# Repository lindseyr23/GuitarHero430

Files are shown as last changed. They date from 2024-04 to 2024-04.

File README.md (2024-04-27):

# Guitar Hero 430
## Rice University ELEC 327 Final Project Spring '24

## Project Description 
This project aims to recreate the experience of playing the iconic Guitar Hero using MSP430 microcontrollers. Inspired by the popular rhythm-based video game, this project combines hardware interfacing, LED visualization, audio processing, and gameplay logic to create an experience playing along with your favorite songs.

Using two TI LaunchPad Kits with MSP430 (MSP-EXP430G2ET), the project simulates the Guitar Hero gameplay. One LaunchPad serves as the game controller, managing gameplay logic and capturing user input, while providing real-time feedback through an LED display. The other LaunchPad controls LED visualizations and audio output for the song.

Upon starting the game, users are greeted with an introduction sequence. They can select song 1 by pressing the green button or song 2 by pressing the blue button. During gameplay, missing too many notes results in a loss sequence. However, achieving a streak of a certain number of notes resets the missed notes counter, akin to the rock meter in Guitar Hero. Successfully completing the entire song triggers a win sequence.

Check out a demo of the project [here](https://youtu.be/caU7hopNlVo)!

## Table of Contents
1. [Project Description](#project-description)
2. [Team Members](#team-members)
3. [Materials](#materials)
4. [File Descriptions](#file-descriptions)
5. [Setting up the Hardware](#setting-up-the-hardware)
   - [LED Game Display Setup Guide](#led-game-display-setup-guide)
   - [LED User Display Setup Guide](#led-user-display-setup-guide)
   - [3D-Printed Strummer & LED Game Display Case Setup Guide](#3D-Printed-Strummer-&-LED-Game-Display-Case-Setup-Guide)
   - [Schematic](#schematic)
6. [Installation](#installation)
7. [References](#references)

### Team Members
- Natalia Mendiola | nm58@rice.edu
- Lindsey Russ     | ltr1@rice.edu
  
---
### Materials

* 2x computers 
* 2x TI LaunchPad Kit with MSP430 ([MSP-EXP430G2ET](https://www.ti.com/lit/ug/slau144k/slau144k.pdf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))
* 2x 330 Ω Resistors
* 1x SunFounder I2C LCD1602 Module _(we used [this](https://www.sunfounder.com/products/i2c-lcd1602-module))_
* 5x Push Buttons _(we used [these](https://www.amazon.com/Gikfun-12x12x7-3-Tactile-Momentary-Arduino/dp/B01E38OS7K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) )_
* SK9822 LED Strips
* Solderless Breadboard
* Jumper wires
* Enameled wire

### Required Software Packages

* **Code Composer Studio (CSS)**
  - Install Code Composer Studio on two separate computers. Download it from [here](https://www.ti.com/tool/download/CCSTUDIO/12.7.0).
* **Python**
  - This project is compatible with Python 3.11.x. Make sure you have Python 3.11.x installed on your system before installing the required packages. To install the required Python packages, run the following command in your terminal or command prompt:
   ```python
   pip install -r requirements.txt
   ```
----
## File Descriptions

### Board 1:

* **Game Logic:**
  - [main.c](./board1/main.c): Handles game logic and user inputs.
    
* **User LED Display Logic:**
  - [rgb_interface_user.c](./board1/rgb_interface_user.c): Controls RGB LEDs via SPI communication.
  - [rgb_interface_user.h](./board1/rgb_interface_user.h): Header file for RGB user interface.
    
* **Scoreboard LCD Display Logic:**
  - [i2c.c](./board1/i2c.c): Initializes and transmits data over the I2C bus.
  - [i2c.h](./board1/i2c.h): Header file for I2C communication.
  - [lcd.c](./board1/lcd.c): Implements functions for interacting with an LCD display using I2C communication.
  - [lcd.h](./board1/lcd.h): Header file for LCD interface.

### Board 2:

* **Game Audio and Visual Logic:**
  - [main.c](./board2/main.c): Handles receiving communication from Board 1 to trigger events on the 5x7 LED screen and play MP3 files

* **LED Game Display Logic:**
  - [rgb_interface.c](./board2/rgb_interface.c): Controls the 5x7 LED Screen via SPI communication
  - [rgb_interface.h](./board2/rgb_interface.h): Header file for RGB interface

* **Audio:**
  - [receive_audio.py](./board2/receive_audio.py): Reads in data from the COM port to trigger the MP3 files playing and stopping
  - [PlaySong.c](./board2/PlaySong.c): Sends out the information to the COM port using UART communication to trigger the python file
  - [PlaySong.h](./board2/PlaySong.h): Header file for PlaySong
  - [Rock_Band_4_Fortunate_Son_Creedence_Clearwater_Revival_Full_Band_HD.mp3](./board2/Rock_Band_4_Fortunate_Son_Creedence_Clearwater_Revival_Full_Band_HD.mp3): Song 1
  - [Guitar_Hero_3_Mississippi_Queen.mp3](./board2/Guitar_Hero_3_Mississippi_Queen.mp3): Song 2
  - [win_sound_effect.mp3](./board2/win_sound_effect.mp3): Winning sound effect
  - [loss_sound_effect.mp3](./board2/loss_sound_effect.mp3): Losing sound effect

---

## Setting up the hardware

### LED Game Display Setup Guide
<div style="text-align:center">
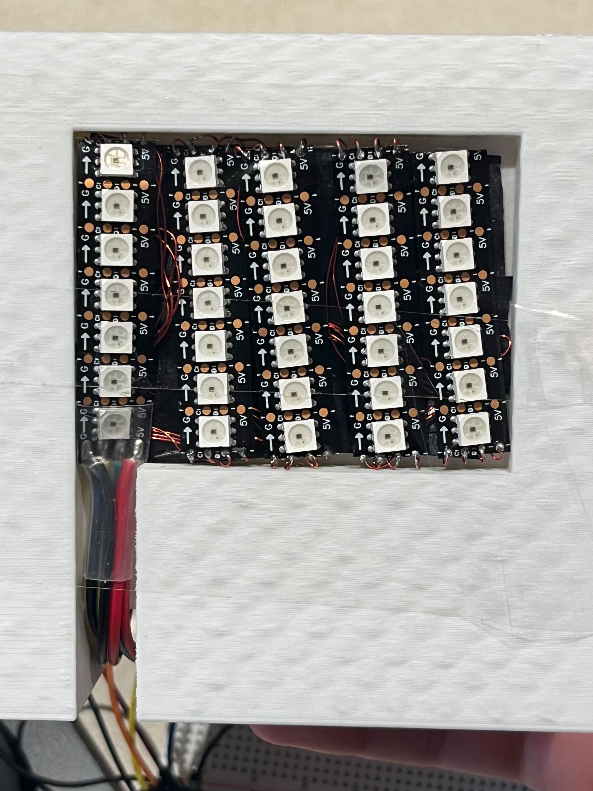
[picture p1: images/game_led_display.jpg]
LED Game Display
  
</div>

#### Components Needed:
   - SK9822 LED strips
   - Jumper wires (male-to-female)
   - Enameled wire
   - Heat shrink tubing
   - Electrical Tape

#### Instructions:
1. **Prepare the LED Strip:**
   - Cut five 7-LED long strips from the SK9822 LED strip.
2. **Solder Jumper Wires:**
   - For only ONE LED strip, solder four jumper wires to one end:
     - G (Ground)
     - C (Clock)
     - D (Data)
     - 5V (Power)
3. **Attach Female Connectors:**
   - (if not already present) Solder female connectors to the other end of the jumper wires for this LED strip.
4. **Connect LED Strips:**
   - For the remaining four strips, connect each strip to the previous one using enameled wire:
     - Connect G to G, C to C, D to D, and 5V to 5V.
     - Hide the enameled wire connections behind the LED strips.
     - Daisy-chain the five LED strips together, ending with the jumper wires side.
5. **Secure Connections:**
   - Use electrical tape to secure the enameled wire connections behind the LED-facing side of the LED strips, forming a 5x7 LED rectangular shape.
   - Use heat shrink tubing to insulate and secure the jumper wire soldered connections.
#### Notes:
   - Handle the soldering iron and heat shrink tubing carefully to prevent injuries or damage to components.

### LED User Display Setup Guide
<div style="text-align:center">
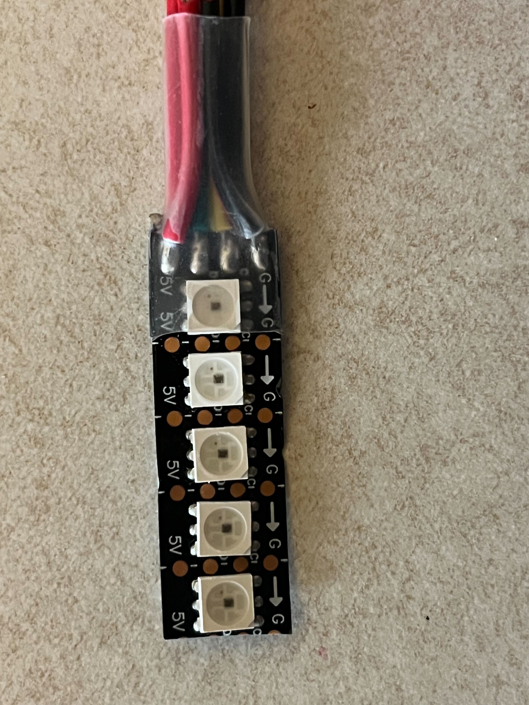
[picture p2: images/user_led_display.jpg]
LED User Display
    
</div>

#### Components Needed:
   - SK9822 LED strips
   - Jumper wires (male-to-female)
   - Heat shrink tubing

#### Instructions:
1. **Prepare the LED Strip:**
   - Cut a 5 LED long strip from the SK9822 LED strip.
2. **Solder Jumper Wires:**
   - Solder four jumper wires to one end of the LED strip:
     - One wire for G (Ground)
     - One wire for C (Clock)
     - One wire for D (Data)
     - One wire for 5V (Power)
3. **Attach Female Connectors:**
   - (if not already present) Solder female connectors to the other end of the jumper wires.
4. **Secure Connections:**
   - Use heat shrink tubing to insulate and secure the soldered connections.
#### Notes:
   - Handle the soldering iron and heat shrink tubing carefully to prevent injuries or damage to components.

### 3D-Printed Strummer & LED Game Display Case Setup Guide:
* [Strumbar STL File](./stl_files/strumbar2b-v3.stl)
* [End Bracket STL File](./stl_files/endbracket-v26.stl)
* [LED Display Holder STL File](./led_display_holder.stl)

3D Print the Strumbar, 2 of the End Brackets, and  the LED Display Holder from the above STL files. The Strumbar and End Brackets may need to be resized, in which case resize them both with the same ratio, ensuring that it is large enough for a button to fit within the notch but not too large so that the strumbar is unable to reach the button. We found that a width of 3 inches worked well for the Strumbar. The brackets for the strummer can be screwed onto a PCB, or taped down to a breadboard. The notch in the strummer is where the button for strumming input should be set up.

Secure the 5x7 LED display within the 3D-printed holder, with the jumper wires going through the notch and routed to the back for connection to the MSP430 acting as board 
2. 

### Schematic

#### Overall Schematic:
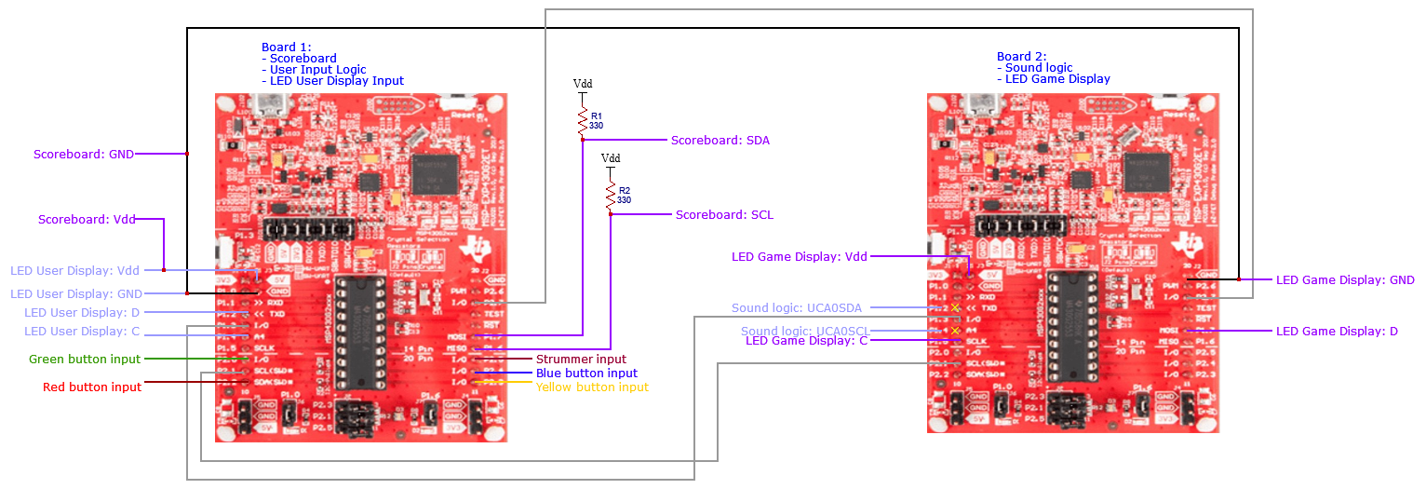
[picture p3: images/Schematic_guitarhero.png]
Overall Schematic


#### Board 1:
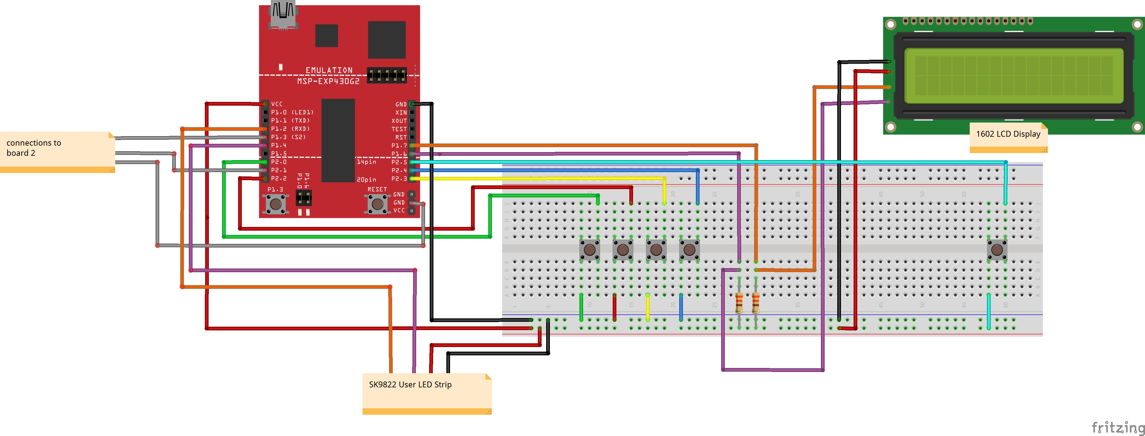
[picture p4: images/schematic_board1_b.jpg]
Board 1


#### Board 2:
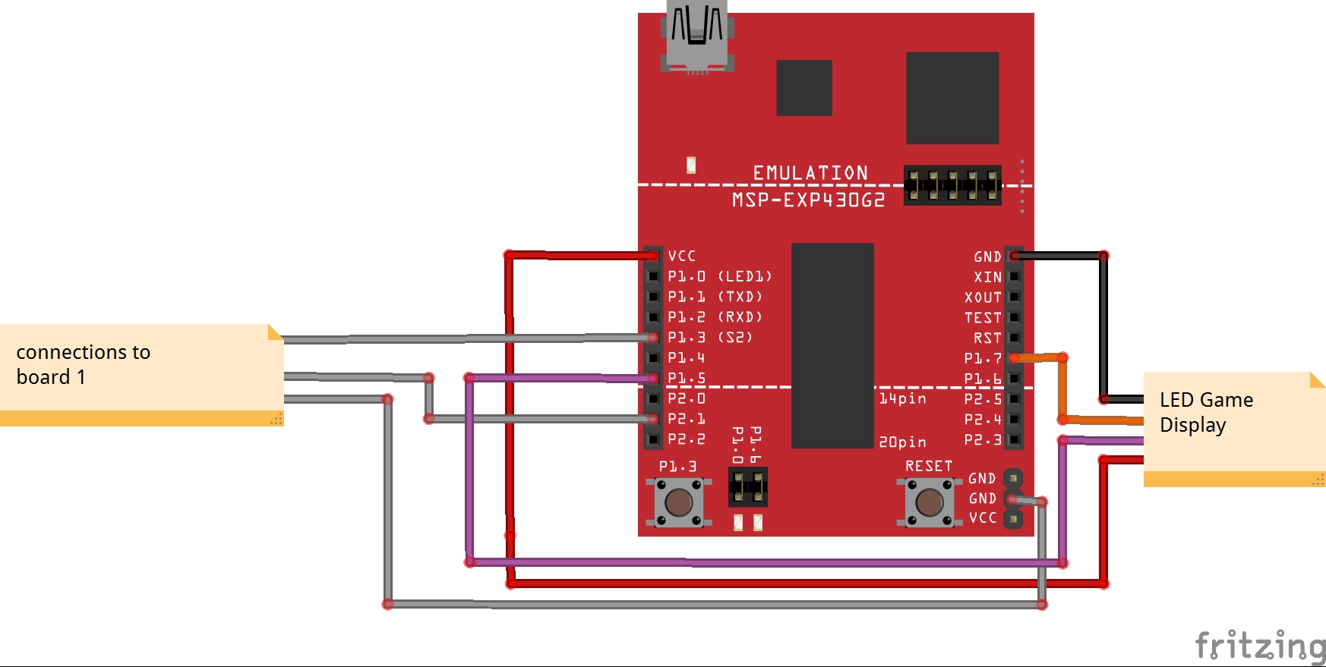
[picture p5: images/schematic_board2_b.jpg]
Board 2


---

## Installation

1. **Set up the Hardware:**
   - Follow the schematics to set up the circuit boards for both LaunchPads.
        -  [Overall Schematic](./images/Schematic_guitarhero.png)
        -  [Board 1 schematic](./images/schematic_board1_b.jpg)
        -  [Board 2 schematic](./images/schematic_board2_b.jpg)

2. **Install Code Composer Studio:**
    - Download and install [Code Composer Studio](https://www.ti.com/tool/download/CCSTUDIO/12.7.0) on your computer.

3. **Create Projects for Each Board:**
   - OpenCode Composer Studio
   - Create a separate project for each board.
   - Set the target device to MSP430G2553 for each project.

4. **Set up the LaunchPads:**
   - Upload the board 2 code to the LaunchPad set up as board 2.
   - Then, upload the board 1 code for LaunchPad set up as board 1.

5. **Run receive_audio.py Script:**
   - On the same computer running board 2 code, run a script named "receive_audio.py".

6. **Have fun!**
   - Start the game, and you'll be greeted with an intro sequence.
   - Choose a song by pressing the green button for song 1 or the blue button for song 2.
   - During gameplay, hitting the buttons correctly will keep the music going. Missing too many notes will lead to a game over sequence.
   - Just like in Guitar Hero, hitting a streak of notes will reset your missed notes counter.
   - Completing the entire song will trigger a win sequence!
  
#### Note: 
   - Feel free to explore and customize the code to add more songs, difficulty levels, or even different instruments!
---

## References
1. _Strumbar - with “finger notches”_ stl file from [Byte Arts](https://www.bytearts.com/strumfixplus).
2. Modified code by Dr. Joseph Young based on [I2C Display and MSP430](https://github.com/andrei-cb/I2C-Display-and-MSP430/tree/master) by Andrei-cb.

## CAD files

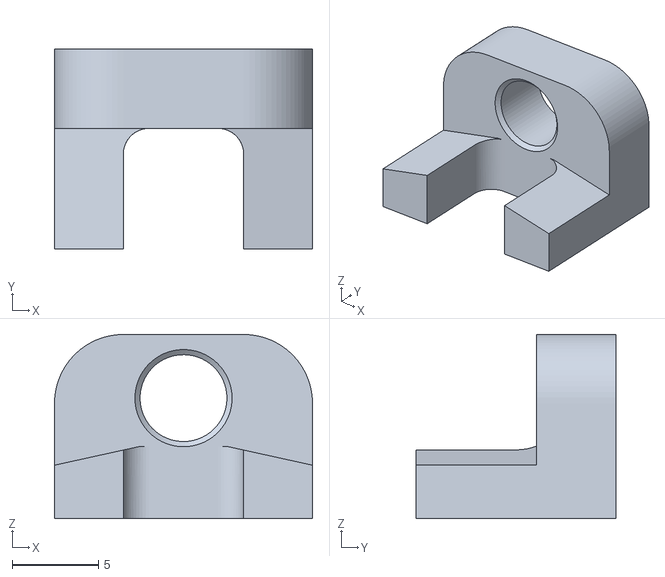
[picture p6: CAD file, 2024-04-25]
stl_files/endbracket-v26.stl
15.0 x 11.6 x 10.7

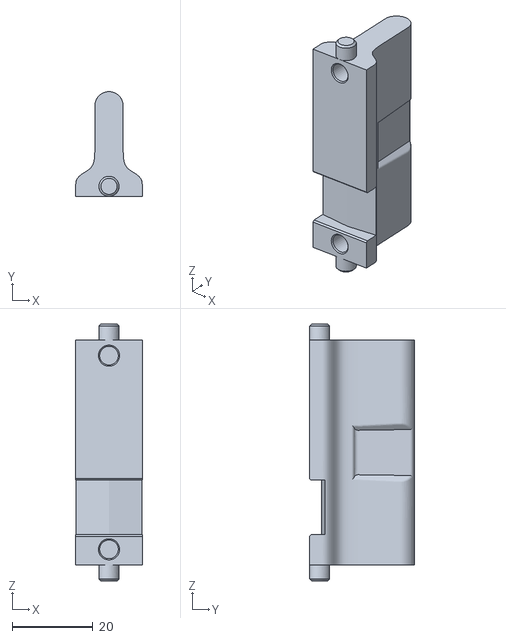
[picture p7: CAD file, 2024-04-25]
stl_files/strumbar2b-v3.stl
16.5 x 26.0 x 63.8

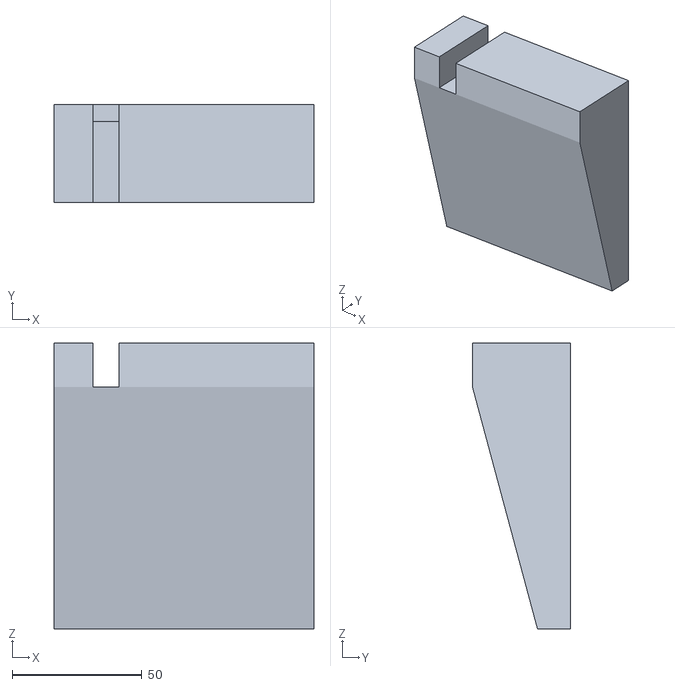
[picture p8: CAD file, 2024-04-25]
stl_files/led_display_holder.stl
100.0 x 37.7 x 110.0

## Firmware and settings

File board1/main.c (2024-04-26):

#include <stdio.h>
#include <string.h>

#include "rgb_interface_user.h"
//------------------------------
#include "lcd.h"
#include "msp430g2553.h"


/*
 * Connections Necessary:
 *
 * Green Button: 2.0 Red 2.2 Yellow 2.3 Blue 2.4
 * Strummer: 2.5
 */
/*
green - 1; red - 2; yellow - 3; blue - 4;
green/red - 5; green/yellow -6; green/blue - 7;
red/yellow - 8; red/blue - 9; yellow/blue - 10;
*/
const unsigned int song1[] = {//Fortunate Son - Creedence Clearwater Revival
                           0,0,0,0,0,0,0,0, //intro
                           0,0,0,0,0,0,0,0,
                           0,0,0,0,0,0,0,0, //
                           0,0,0,0,0,0,0,0,
                            3,4,4,4,4,4,4,4, //0:07
                            2,3,3,3,3,3,3,3,
                            1,3,3,3,3,3,3,3,
                            1,2,2,2,3,1,1,1,
                            3,4,4,4,4,4,4,4,
                            2,3,3,3,3,3,3,3,
                            1,3,3,3,3,3,3,3,
                            1,2,2,2,3,1,1,1,
                            9,0,0,9,0,9,9,0, //verse 1? 0:21
                            6,0,0,6,0,6,0,0,
                            10,0,0,10,0,10,0,0,
                            9,0,4,3,0,2,3,2,
                            2,2,2,2,2,2,2,2,
                            6,0,0,6,0,6,0,0,
                            10,0,0,10,0,10,0,0,
                            2,2,1,2,3,2,4,2,
                            2,2,2,2,2,2,2,2, //0:35
                            1,1,1,3,3,3,3,3,
                            2,2,2,4,4,4,3,3,
                            2,1,3,1,4,1,2,1,
                            3,3,3,3,3,3,3,3,//0:35
                            1,1,1,3,3,3,3,3,
                            2,2,2,4,4,4,3,3,
                            1,1,4,4,3,2,1,3,
                            2,2,2,2,2,2,2,2,//0:36
                            1,1,1,3,3,3,3,3,
                            2,2,2,4,4,4,3,3,
                            1,1,4,4,3,2,1,3,
                            2,2,2,2,2,2,2,2,
                            2,2,2,2,2,2,2,2,//0:43
                            1,1,1,3,3,3,3,3,
                            2,2,2,4,4,4,3,3,
                            1,1,4,4,3,2,1,3,
                            2,2,2,2,2,2,2,2,//0:50
                            6,0,0,6,0,6,0,0,
                            10,0,0,10,0,10,0,0,
                            9,0,4,3,0,2,3,2,
                            2,2,2,2,2,2,2,2, //0:57
                            6,0,0,6,0,6,0,0,
                            10,0,0,10,0,10,0,0,
                            9,0,4,3,0,2,3,2,
                            2,2,2,2,2,2,2,2,//1:04
                            1,1,1,3,3,3,3,3,
                            2,2,2,4,4,4,3,3,
                            1,1,4,4,3,2,1,3,
                            2,2,2,2,2,2,2,2,
                            1,1,1,3,3,3,3,3,
                            2,2,2,4,4,4,3,3,
                            1,1,4,4,3,2,1,3,
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
                            2,2,2,2,2,2,2,2,//1:48 it aint me
                             1,1,1,3,3,3,3,3,
                             2,2,2,4,4,4,3,3,
                             1,1,4,4,3,2,1,3,
                             2,2,2,2,2,2,2,2,
                             1,1,1,3,3,3,3,3,
                             2,2,2,4,4,4,3,3,
                             1,1,4,4,4,4,1,3,
                             2,2,2,2,2,2,2,2,
                             1,1,1,3,3,3,3,3,
                             2,2,2,4,4,4,3,3,
                             1,1,4,4,4,4,1,3,
                             2,2,2,2,2,2,2,2,
                             1,1,1,3,3,3,3,3,
                             2,2,2,4,4,4,3,3,
                             1,1,4,4,4,4,1,3,
                             2,2,2,2,2,2,2,2,
                             0,0,0,0,0,0,0,0};

const unsigned int songLength1 = sizeof(song1) / sizeof(song1[0]);

unsigned int song2[] = {//Mississippi Queen - Mountain
                        0,0,0,0,0,0,0,0, //into
                        0,0,0,0,0,0,0,0,
                        0,0,0,0,0,1,2,4,
                        2,2,2,0,0,0,0,0,
                        0,0,0,0,0,1,2,4,
                        2,2,2,0,0,0,0,0,
                        3,4,3,2,1,1,3,1    //0:15
                        0,1,2,3,4,4,2,2,
                        1,2,3,4,1,1,2,3
//                        3,4,3,2,1,1,2,3,
//                        5,5,0,0,0,0,0,0, //0:22
//                        0,1,4,1,2,2,3,3, //0:24
//                        5,0,6,0,6,6,6,6,
//                        0,1,4,1,2,2,2,2,
//                        5,0,6,0,6,6,6,6,
//                        0,1,4,1,2,2,3,3,
//                        5,0,6,0,6,6,6,6,
//                        0,1,4,1,2,2,2,2,
//                        8,0,9,9,9,9,9,9,//0:36
//                        0,2,3,2,3,3,4,4,
//                        8,0,9,9,9,9,9,9,
//                        0,0,0,2,3,2,4,4,
//                        5,0,6,0,6,6,6,6, //0:42
//                        0,1,4,1,2,2,2,2

                                        //0:50 changes slightly
};

const unsigned int songLength2 = sizeof(song2) / sizeof(song2[0]);

volatile unsigned int current_note;
volatile unsigned int missed_note;
volatile unsigned int streak;

int user_LED_1;
int user_LED_2;
int user_LED_3;
int user_LED_4;
int button_press_detected;
int strummer;
int score;
int Q=6;
int duration_counter;

volatile unsigned int curr_note;

int song; //takes 1 for song1, 2 for song 2
int debounce_counter;

void check_input(){

    if (song == 1){
        curr_note = song1[current_note];
    }
    else if (song == 2){
       curr_note = song2[current_note];
    }

        switch(curr_note) { //checks if note is correct
            case 1: //green
                if (1 == user_LED_1 & 0 == user_LED_2 & 0 == user_LED_3 & 0 == user_LED_4){
                    score += 10;
                    streak++;
                }
                else {
                    missed_note++;
                    streak = 0;
                }
                break;
            case 2://red
                if (0 == user_LED_1 & 1 == user_LED_2 & 0 == user_LED_3 & 0 == user_LED_4){
                    score += 10;
                    streak++;
                }
                else {
                    missed_note++;
                    streak = 0;
                }
                break;
            case 3: //yellow
                if (0 == user_LED_1 & 0 == user_LED_2 & 1 == user_LED_3 & 0 == user_LED_4){
                    score += 10;
                    streak++;
                }
                else {
                    missed_note++;
                    streak = 0;
                }
                break;
            case 4: //blue
                if (0 == user_LED_1 & 0 == user_LED_2 & 0 == user_LED_3 & 1 == user_LED_4){
                    score += 10;
                    streak++;
                }
                else {
                    missed_note++;
                    streak = 0;
                }
                break;
            case 5: //green/red
                if (1 == user_LED_1 & 1 == user_LED_2 & 0 == user_LED_3 & 0 == user_LED_4){
                    score += 10;
                    streak++;
                }
                else {
                    missed_note++;
                    streak = 0;
                }
                break;
            case 6: //green/yellow
                if (1 == user_LED_1 & 0 == user_LED_2 & 1 == user_LED_3 & 0 == user_LED_4){
                    score += 10;
                    streak++;
                }
                else {
                    missed_note++;
                    streak = 0;
                }
                break;
            case 7: //green/blue
                if (1 == user_LED_1 & 0 == user_LED_2 & 0 == user_LED_3 & 1 == user_LED_4){
                    score += 10;
                    streak++;
                }
                else {
                    missed_note++;
                    streak = 0;
                }
                break;
            case 8: //red/yellow
                if (0 == user_LED_1 & 1 == user_LED_2 & 1 == user_LED_3 & 0 == user_LED_4){
                    score += 10;
                    streak++;
                }
                else {
                    missed_note++;
                    streak = 0;
                }
                break;
            case 9: //red/blue
                if (0 == user_LED_1 & 1 == user_LED_2 & 0 == user_LED_3 & 1 == user_LED_4){
                    score += 10;
                    streak++;
                }
                else {
                    missed_note++;
                    streak = 0;
                }                
                break;
            case 10:// yellow/blue
                if (0 == user_LED_1 & 0 == user_LED_2 & 1 == user_LED_3 & 1 == user_LED_4){
                    score += 10;
                    streak++;
                }
                else {
                    missed_note++;
                    streak = 0;
                }
                break;
        }//end of case

}

void play_song1(int a){ // if a is 1 it starts the song, if a is 0 it stops the song
    if(a==1){
        P2OUT |= BIT1; //send to board2 from p2.1
    }
    else{
        P2OUT &= ~BIT1; //send to board2 from p2.1 
    }
}

void play_song2(int a){// if a is 1 it starts the song, if a is 0 it stops the song
    if(a==1){
        P1OUT |= BIT3; //send to board2 from p1.3
    }
    else{
        P1OUT &= ~BIT3; //send to board2 from p1.3
    }
}

void init_buttons() {
    P2DIR &= ~(BIT0 + BIT2 + BIT3 + BIT4 + BIT5); // set to input
    P2REN |= BIT0 + BIT2 + BIT3 + BIT4 + BIT5; // enable pullup/down resistors
    P2OUT |= BIT0 + BIT2 + BIT3 + BIT4 + BIT5; // set resistors to pull up

    P2IES |= BIT0 + BIT2 + BIT3 + BIT4 + BIT5; // listen for high to low transitions
    P2IFG &=  ~(BIT0 + BIT2 + BIT3 + BIT4 + BIT5); // clear any pending interrupts
    P2IE |= BIT0 + BIT2 + BIT3 + BIT4 + BIT5; // enable interrupts for these pins
}

void init_board_communication() { // 1.1 (accept_input) input, 2.1 (play_song1) output, 1.3 (play_song2) output

    P1DIR &= ~BIT1; // set 1.1 to input

    P2DIR |= BIT1; // set 2.1 to output
    P1DIR |= BIT3; // set 1.3 to output

    //initialize playsound to 0 to not play anything
    P2OUT &= ~BIT1;
    P1OUT &= ~BIT3;
}
//global variables
void set_temperature(unsigned int led1, unsigned int led2, unsigned int led3, unsigned int led4, unsigned int led5);

void init_timerA(void)
{
    TA0CTL |= TACLR;
    TA0CCTL0 = CCIE; //interrupt enable Timer 0
    TA0CCR0 = 4000;    //set up Timer 0
    TA0CTL |= TASSEL_1 + MC_1 + ID_0;
}


enum state_enum {Intro, Game, Lost, Win} state; // enum to describe state of system


int main()
{
    WDTCTL = WDTPW + WDTHOLD; // Stop watchdog


    rgb_init_spi(); //from rgb_interface.c

    __enable_interrupt(); // enable interrupts

    LcdInit(); // initialize LCD display

    init_buttons();
    init_board_communication();
    init_timerA();

    current_note = 0;
    score = 0;
    duration_counter = 0;
    char game_song_text[20]; // Buffer for display text

    state = Intro;

    // Display introductory text on LCD
    LcdSetPosition(2,2); //row, rect  start
    LcdWriteString("Press G or B");

    LcdSetPosition(1,2);
    LcdWriteString("GuitarHero 430");

    // Stop playing any ongoing songs
    play_song1(0);
    play_song2(0);

    while (1)
    {
        if (state == Intro)
        {
            // Display introductory text on LCD
            LcdSetPosition(2,1); //row, rect  start
            LcdWriteString(" Press G or B  ");

            LcdSetPosition(1,1);
            LcdWriteString(" GuitarHero 430  ");

            if (user_LED_1) //if green is pressed
            {
                play_song1(1); //starts playing song 1
                song = 1;
                state = Game;
                current_note = 0;
                duration_counter = 0;
                missed_note = 0;
            }
            else if (user_LED_4)// if blue is pressed
            {
                play_song2(1); //starts playing song 2
                song = 2;
                state = Game;
                current_note = 0;
                duration_counter = 0;
                missed_note = 0;
            }
        }//end of intro
        else if (state == Game)
                {
                    if (user_LED_1 & user_LED_2 & user_LED_3 & user_LED_4) //press all buttons to end the game
                    {
                        play_song1(0); //ends the song
                        play_song2(0); //ends the song
                        state = Intro;
                    }
                    if (strummer) // Check if the strummer is activated
                    {
                        check_input();
                    }

                    if (streak > 6) // Reset missed_note counter if streak exceeds 6
                    {
                        missed_note = 0;
                    }

                    //Check if current note matches the length of the song to determine win state
                    if (((song == 1) && (current_note == songLength1)) || ((song == 2) && (current_note == songLength2))) {
                        state = Win;
                    }
                    // Check if the missed_note counter reaches 40 to determine loss state
                    if (missed_note == 40)
                    {
                        state = Lost;
                        missed_note = 0;
                    }

                    // Format score into a string for display on LCD
                    snprintf(game_song_text, sizeof(game_song_text), "Score: %d", score); // Format score into string
                    strcat(game_song_text, "                "); // Append spaces to clear any previous text


                    // Display score on LCD
                    LcdSetPosition(1,1); //row, rect 
                    LcdWriteString(game_song_text); // Write score to LCD
                    LcdSetPosition(2,1); 
                    LcdWriteString("                    ");// Clear the second row of LCD (20 character space)

                }//end of game state

                if (state == Lost)
                {
                    // Clear the LCD display
                    LcdSetPosition(1,1); //row, rect  
                    LcdWriteString("                    ");//20 character space
                    LcdSetPosition(2,1); //row, rect  
                    LcdWriteString("                    ");//20 character space

                    // Display "Better Luck" message on LCD
                    LcdSetPosition(1,2); //row, rect  
                    LcdWriteString("Better Luck");
                    LcdSetPosition(2,2); //row, rect  
                    LcdWriteString("Next Time!!");//20 character space

                    // Check if a button press is detected to return to the Intro state
                    if (button_press_detected) 
                    {
                        // Reset game state and variables
                        song = 0;
                        current_note = 0;
                        play_song1(0); //signals end of win
                        play_song2(0); //signals end of win

                        // Clear the LCD display
                        LcdSetPosition(1,1); //row, rect
                        LcdWriteString("                    ");//20 character space
                        LcdSetPosition(2,1); //row, rect
                        LcdWriteString("                    ");//20 character space

                        // Display introductory text on LCD
                        LcdSetPosition(2,1); //row, rect  start
                        LcdWriteString(" Press G or B  ");

                        LcdSetPosition(1,1);
                        LcdWriteString(" GuitarHero 430  ");


                        state = Intro;
                    }
                }//end of loss state
                if (state == Win)
                {
                    // Clear the LCD display
                    LcdSetPosition(1,1); //row, rect  
                    LcdWriteString("                    ");//20 character space
                    LcdSetPosition(2,1); //row, rect  
                    LcdWriteString("                    ");//20 character space
                    LcdSetPosition(1,4); //row, rect
                     // Display "You Rock!!! Awesome Playing!" message on LCD  
                    LcdWriteString("You Rock!!!");
                    LcdSetPosition(2,1); //row, rect  start
                    LcdWriteString("Awesome Playing!");//20 character space

                    // Check if a button press is detected to return to the Intro state
                    if (button_press_detected) //if green is pressed
                    {
                        // Reset game state and variables
                        song = 0;
                        current_note = 0;
                        play_song1(0); //signals end of win
                        play_song2(0); //signals end of win
                        state = Intro;
                    }
                }//end of win state

        set_temperature(user_LED_1, user_LED_2, user_LED_3, user_LED_4, 0); //displays user input
        LPM3;
    }//end of while

//return 0;

} //end of main

#if defined(__TI_COMPILER_VERSION__) || defined(__IAR_SYSTEMS_ICC__)
#pragma vector=PORT2_VECTOR
__interrupt void button(void)
#elif defined(__GNUC__)
void __attribute__ ((interrupt(PORT2_VECTOR))) button (void)
#else
#error Compiler not supported!
#endif
{
        if(P2IFG & BIT0)//checks port 2.0
        {
            if(P2IES & BIT0) { // falling edge detected - button pressed
                if (debounce_counter == 0){
                   button_press_detected = 1;
                    user_LED_1 = 1;
                    P2IES &= ~BIT0; //change edge to rising (button release)
                }
            } else {// rising edge detected - button released
                user_LED_1 = 0;
                P2IES |= BIT0; // Change edge to falling (button press) 
            }
            P2IFG &= ~BIT0; // clear interrupt flag for button
        }

        if(P2IFG & BIT2)//checks port 2.2
        {
            if(P2IES & BIT2) { // falling edge detected - button pressed
                if (debounce_counter == 0){
                    button_press_detected = 1;
                    user_LED_2 = 1;
                    P2IES &= ~BIT2; // change edge to rising (button release)
                }
            } else { // rising edge detected - button released
                user_LED_2 = 0;
                P2IES |= BIT2; // Change edge to falling (button press)
            }
            P2IFG &= ~BIT2; // clear interrupt flag for button
        }
       if(P2IFG & BIT3)//checks port 2.3
       {
           if(P2IES & BIT3) {
               if (debounce_counter == 0){  // falling edge detected - button pressed
                    button_press_detected = 1;
                    user_LED_3 = 1;
                    P2IES &= ~BIT3; // change edge to rising (button release)
               }
           } else {// rising edge detected - button released
               user_LED_3 = 0;
               P2IES |= BIT3; // Change edge to falling (button press)
           }
           P2IFG &= ~BIT3; // clear interrupt flag for button
       }

       if(P2IFG & BIT4)//checks port 2.4
       {
           if(P2IES & BIT4) {
               if (debounce_counter == 0){// falling edge detected - button pressed
                   button_press_detected = 1;
                   user_LED_4 = 1;
                    P2IES &= ~BIT4; // change edge to rising (button release)
               }
           } else { // rising edge detected - button released
               button_press_detected = 1;
               user_LED_4 = 0;
               P2IES |= BIT4; // change edge back to falling (button press)
           }
           P2IFG &= ~BIT4; // clear interrupt flag for button
       }
       //strum logic
       if(P2IFG & BIT5)//checks port 2.5
       {
           if(P2IES & BIT5) {
               if (debounce_counter == 0){
                   button_press_detected = 1;
               // falling edge detected - button pressed
               strummer = 1;
               P2IES &= ~BIT5; // change edge to rising (button release)
               }
           } else { // rising edge detected - button released
               strummer = 0;
               P2IES |= BIT5; // change edge back to falling (button press)
           }
           P2IFG &= ~BIT5; // clear interrupt flag for button
       }

    __bic_SR_register_on_exit(LPM3_bits); // exit LPM3 when returning to program (clear LPM3 bits)
}// end of port 2 ISR


#pragma vector=TIMER0_A0_VECTOR
__interrupt void Timer_A(void)
{
    if (state == Game | state == Intro)  // Check if the game is in Game or Intro state
    {
        duration_counter++;
        if (duration_counter > Q){
            current_note++; //move to the next note
            duration_counter = 0;
        }
    }
}//end of A0 ISR

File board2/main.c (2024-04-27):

#include <msp430.h>
#include <stdint.h>
#include <stdbool.h>
#include "rgb_interface.h"
#include "PlaySong.h"
/**
 * main.c
 */

#define buffer 8

extern unsigned int song1_fortunate_son[]; // The array representing Fortunate Son
extern const unsigned int songLength1;//  The length of the array

unsigned int color_intro[] = {0,11,0,11,0,11,0,11,0}; // The array representing the introduction display

extern unsigned int song2_mississippi_queen[]; // The array representing Mississippi Queen
extern const unsigned int songLength2;//   The length of the array


//note durations for each
const unsigned int introDuration = 10;
const unsigned int song1Duration = 6; //want every 2 notes to  be 133 bpm. beat is the eigth note
const unsigned int song2Duration = 6; //want every 2 notes to  be ~140 bpm. beat is the eigth note

// The way that the colors are represented in the screen LED Display
extern const uint8_t green;
extern const uint8_t red;
extern const uint8_t yellow;
extern const uint8_t blue;
extern const uint8_t orange;
// The individual LEDs in the display are all defined here
//----------------------
volatile unsigned int green_next;
volatile unsigned int g_led1;
volatile unsigned int g_led2;
volatile unsigned int g_led3;
volatile unsigned int g_led4;
volatile unsigned int g_led5;
volatile unsigned int g_led6;
volatile unsigned int g_led7;
//----------
volatile unsigned int red_next;
volatile unsigned int r_led1;
volatile unsigned int r_led2;
volatile unsigned int r_led3;
volatile unsigned int r_led4;
volatile unsigned int r_led5;
volatile unsigned int r_led6;
volatile unsigned int r_led7;
//---------
volatile unsigned int yellow_next;
volatile unsigned int y_led1;
volatile unsigned int y_led2;
volatile unsigned int y_led3;
volatile unsigned int y_led4;
volatile unsigned int y_led5;
volatile unsigned int y_led6;
volatile unsigned int y_led7;
//---------
volatile unsigned int blue_next;
volatile unsigned int b_led1;
volatile unsigned int b_led2;
volatile unsigned int b_led3;
volatile unsigned int b_led4;
volatile unsigned int b_led5;
volatile unsigned int b_led6;
volatile unsigned int b_led7;
//---------
volatile unsigned int orange_next;
volatile unsigned int o_led1;
volatile unsigned int o_led2;
volatile unsigned int o_led3;
volatile unsigned int o_led4;
volatile unsigned int o_led5;
volatile unsigned int o_led6;
volatile unsigned int o_led7;
//----------------------

volatile unsigned int new_g;
volatile unsigned int new_r;
volatile unsigned int new_y;
volatile unsigned int new_b;
volatile unsigned int new_o;
volatile unsigned int curr_note;


volatile unsigned int counter = 0; // Keeps track of Timer A so we can implement note durations


unsigned int current_note; // Keeps track of current note
unsigned int songLength; // Keeps track of the song Length
//keeps track of notes in array
unsigned int *note_position; // Pointer to the note position

enum state_enum {Intro, Game, Lost, Win} state; // enum to describe state of system

int next = 0;
extern int ready_for_next; //flag to be ready for next
int note_change; // flag that note change occured
int shift_leds_flag; // flag that LEDS should be shifted
int play_song1; // Keeps track of if song1 is playing
int play_song2; // Keeps track of if song2 is playing
int stop_song; // Keeps track of if we receive indication that the song should stop

void next_note(int green_next, int red_next, int yellow_next, int blue_next, int orange_next)
{
    /*
     * Sends the next note to the LED array
     */
    rgb_send_start();
    set_green(g_led1, g_led2, g_led3, g_led4, g_led5, g_led6, g_led7);
    set_red(r_led1, r_led2, r_led3, r_led4, r_led5, r_led6, r_led7);
    set_yellow(y_led1, y_led2, y_led3, y_led4, y_led5, y_led6, y_led7);
    set_blue(b_led1, b_led2, b_led3, b_led4, b_led5, b_led6, b_led7);
    set_orange(o_led1, o_led2, o_led3, o_led4, o_led5, o_led6, o_led7);
    rgb_send_end();
}
//----------------------.

// Initialization Functions
void init_timerA(void)
{
    TA0CTL |= TACLR;
    TA0CCTL0 = CCIE; //interrupt enable Timer 0
    TA0CCR0 = 4000;    //set up Timer 0
    TA0CTL |= TASSEL_1 + MC_1 + ID_0;
}

void init_buttons() {
    P2DIR &= ~(BIT0 + BIT2 + BIT3 + BIT4 + BIT5); // set to input
    P2REN |= BIT0 + BIT2 + BIT3 + BIT4 + BIT5; // enable pullup/down resistors
    P2OUT |= BIT0 + BIT2 + BIT3 + BIT4 + BIT5; // set resistors to pull up

    P2IES |= BIT0 + BIT2 + BIT3 + BIT4 + BIT5; // listen for high to low transitions
    P2IFG &=  ~(BIT0 + BIT2 + BIT3 + BIT4 + BIT5); // clear any pending interrupts
    P2IE |= BIT0 + BIT2 + BIT3 + BIT4 + BIT5; // enable interrupts for these pins
}

void init_board_communication() { // 2.1 (play_song1) output, 1.3 (play_song2) output

    // Set up the input pins
    P2DIR &= ~BIT1; // Set pin 2.1 to input to receive play_song1
    P1DIR &= ~BIT3; // Set pin 1.3 to input to receive play_song2


    // listen for low to high transition to start the songs
    P2IES &= ~BIT1;
    P1IES &= ~BIT3;



    // enable interrupts for these pins
    P2IE |= BIT1;
    P1IE |= BIT3;

    P2REN |= BIT1;
    P2OUT |= BIT1;


    // make sure it starts at low
    P2IN &= ~BIT1;
    P1IN &= ~BIT3;

    // clear any pending interrupts
    P2IFG &= ~BIT1;
    P1IFG &= ~BIT3;

}
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

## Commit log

2024-04-12 got sound working!
    [main.obj, serial_comm.obj]
2024-04-14 timers not 100% sync
2024-04-18 started working on mains for separate boards
2024-04-19 added inputs and outputs for Board 2
2024-04-19 worked more on Board 1 logic and tested the inputs to Board 2
2024-04-21 in person modifications for board 2, adding songs, debugging
2024-04-21 Schematic of setup using 2 two MSP-EXP430G2ET
2024-04-23 working scoreboard. missing songs
    [i2c.c, lcd.c, main.c]
2024-04-24 working board 1
2024-04-25 houston we got a problem
    [lcd.c, main.c]
2024-04-25 Added Timer A to board 1
2024-04-25 stl and txt
    [led_display_holder.stl]
2024-04-25 moved sound files to the board2 folder
2024-04-25 uploaded strumbar stl file
    [strumbar2b-v3.stl]
2024-04-25 Added endbracket stl file
    [endbracket-v26.stl]
2024-04-26 board specific schematics
2024-04-26 updated schematics
2024-04-26 board 2 slight change
2024-04-26 Have fun :)
    [endbracket-v26.stl, led_display_holder.stl, main.obj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]
2024-04-27 added comments to board2 and changed the name of the stl_files folder
    [endbracket-v26.stl, led_display_holder.stl, strumbar2b-v3.stl]
